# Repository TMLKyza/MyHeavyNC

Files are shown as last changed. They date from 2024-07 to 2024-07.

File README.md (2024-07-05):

# MyHeavyNC

Welcome to MyHeavyNC, a redesigned version of PrintNC. I'm open to suggestions and feedback on the project!

## About

First and foremost, I am **NOT** an engineer. I am a theoretical physicist who attempted to become an automation engineer but was unsuccessful in admission exams. As a result, there may be errors and areas for improvement in this project.

## File Structure and Features

The file structure is straightforward. In the `LCNC-config` folder, you will find everything you need to copy and paste into `~/linuxcnc/config` to get it working. This folder also contains a rewritten post processor for my cooling setup and partially rewritten Fusion360 probing routines.
Another thing I didn't like about how it was handled was tool-length-offsets and so I modifyed `M6remap` macro. Now, you only need to touch off the spindle cone on the tool setter and write the absolute measurement into the `.ini` file.
Because of this, I found no necessity to use the touchoff procedure used by QtDragon, so I rewired the button to the `M6` command.

To install in LinuxCNC all the above additions:
1. copy the `m6-remap` folder into ~/linuxcnc/nc_files/examples/
2. copy `f360-subroutines` into \~/linuxcnc/nc_files/examples
3. import in Fusion the new post processor `LCNC.cps`

## Why Choose This Project?

MyHeavyNC takes everything good from the original PrintNC project and makes it stiffer, heavier, and more powerful. The result is the ability to mill up to 100 cm³/min in aluminium and cut steel at 6000 rpm.
You can check out the performance of the machine on my [Instagram profile](https://www.instagram.com/diymachining/).

## Interesting details
1. I used a UHPC mix specifically made to anchor down machines that produce a lot of vibrations, it's also water and oil-resistant. The company that makes it is called Draco and the product is Flueco 75 if you wish to give a look at the datasheet.
2. The VFD I use is a really important component imo, I recently bought a Folinn BD600 with SVC. I had to sacrifice some top end as it has a maximum output frequency of 300hz in SVC but I gained a lot of torque everywhere in the rpm range. It's a bit more expensive but it makes a night and day difference.

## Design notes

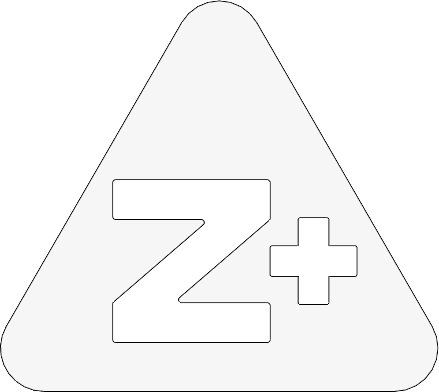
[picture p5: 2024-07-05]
LCNC-config/qtvcp/screens/qtdragon/images/z_plus_jog_button.png

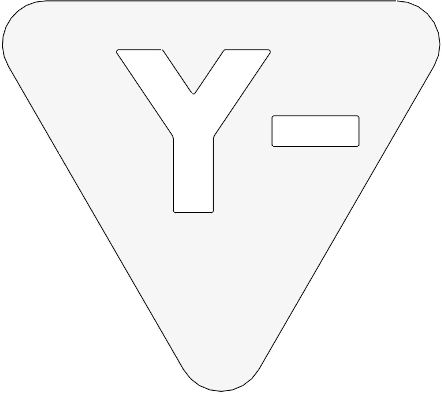
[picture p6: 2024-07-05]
LCNC-config/qtvcp/screens/qtdragon/images/y_minus_jog_button.png

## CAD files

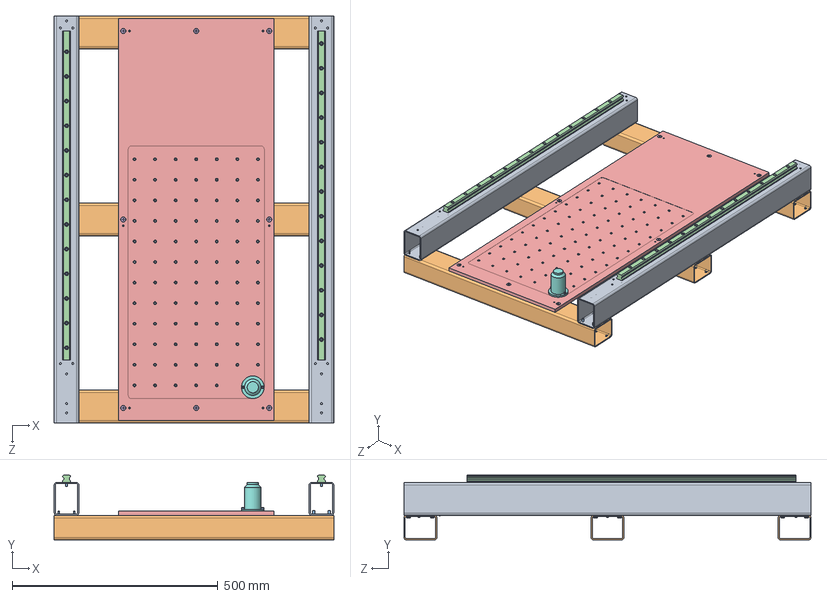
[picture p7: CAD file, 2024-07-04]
CAD/parts/Base/Base_assembly.SLDASM
680.0 x 158.0 x 990.0 mm
base_longitudinal_beams x 2
base_trasverse_beams x 3
socket head cap screw_am x 52
HRG25Rail x 2
socket countersunk head screw_am x 8
socket set screw cup point_am x 6
toolSetter^Base_assembly
hole_caps x 82

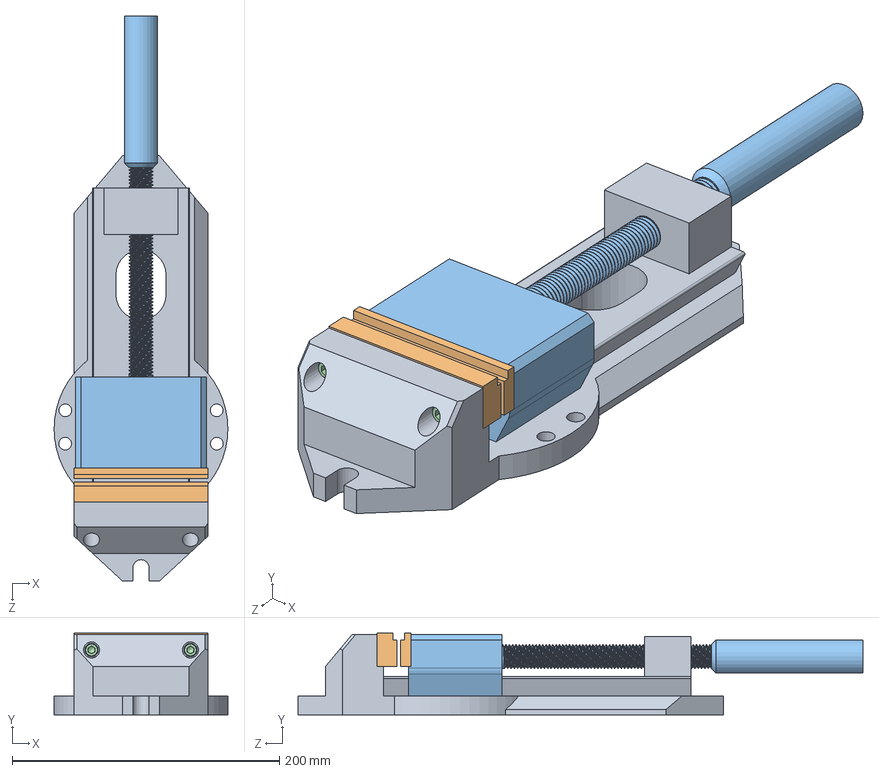
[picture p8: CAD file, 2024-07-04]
CAD/Users/CAD/Documents/SOLIDWORKS/vice/Vice.SLDASM
130.0 x 61.0 x 422.7 mm
base
jaws x 2
movingVice^Vice
socket head cap screw_am x 4

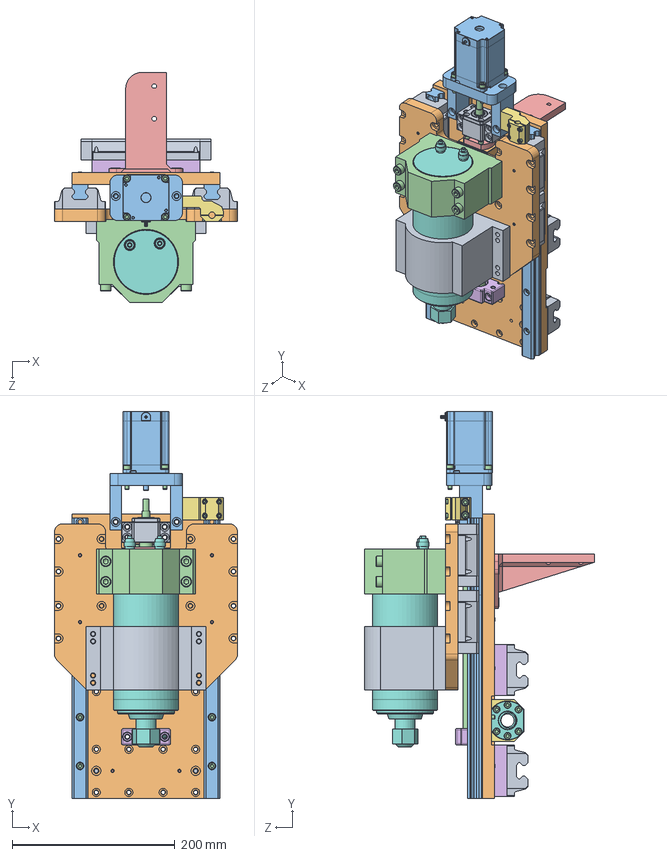
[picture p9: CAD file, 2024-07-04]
CAD/parts/Zaxis/ZAxis-assembly.SLDASM
225.2 x 475.8 x 283.0 mm
HRG25_Carriage x 8
mainPlate
HRG25Rail x 4
socket head cap screw_am x 34
socket set screw cup point_am x 8
XcarriageSpacer x 2
SFU16nutHolder.step
SFU1605-BallNut.step
BK10.step
SFU1204-nutCasing
nema23.step
SFU
SFU1204-BallNut.step
BF10_b___y___(___).STEP
608ZZ_b__.STEP
2_2kw_spindle v2.step
newSpindleSupport
spindlePlate
motorSupport
OldSpindleBracket.step
ZCableChainSupport.step
socket countersunk head screw_am x 3
Zsensor support^ZAxis-assembly

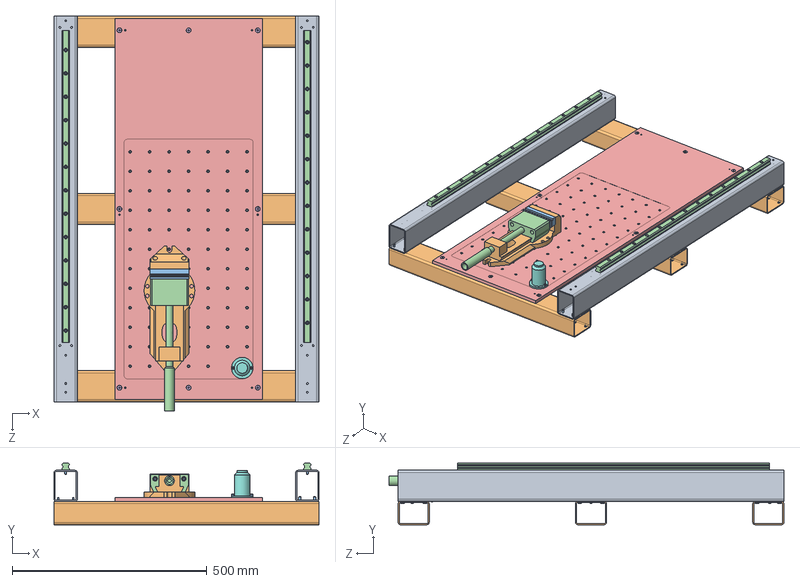
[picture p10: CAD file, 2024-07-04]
CAD/Users/CAD/Documents/SOLIDWORKS/Router/parts/Base/Base_assembly.SLDASM
680.0 x 158.0 x 1013.1 mm
base_longitudinal_beams x 2
base_trasverse_beams x 3
socket head cap screw_am x 56
HRG25Rail x 2
socket countersunk head screw_am x 8
socket set screw cup point_am x 6
toolSetter^Base_assembly
hole_caps x 82
base
jaws x 2
movingVice^Vice

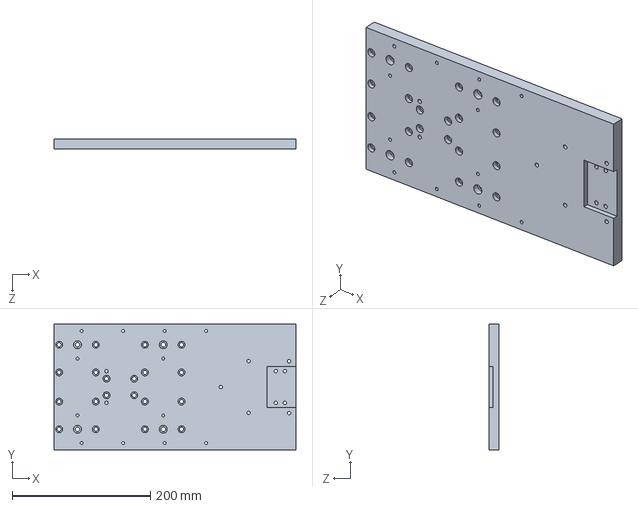
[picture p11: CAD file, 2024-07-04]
CAD/Users/CAD/Documents/SOLIDWORKS/Router/parts/Zaxis/mainPlate.SLDPRT
350.0 x 182.2 x 15.0 mm

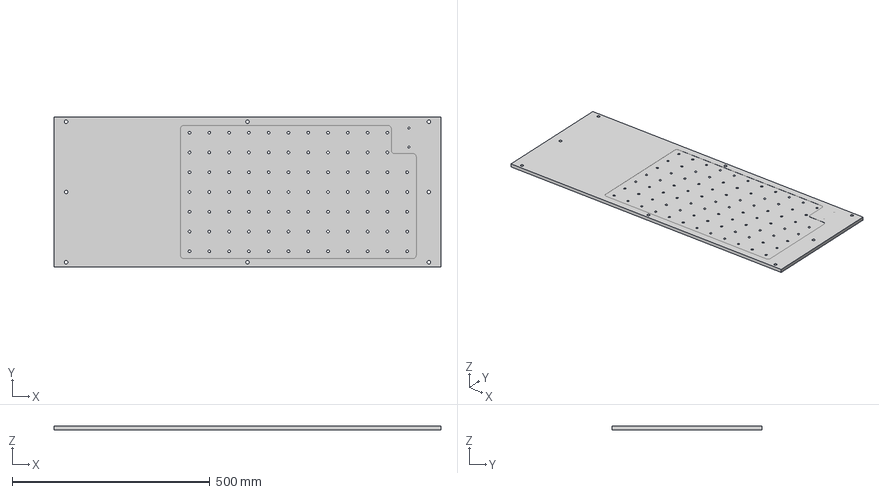
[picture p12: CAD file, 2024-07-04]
CAD/machineBed v8.step
978.0 x 379.0 x 10.0 mm

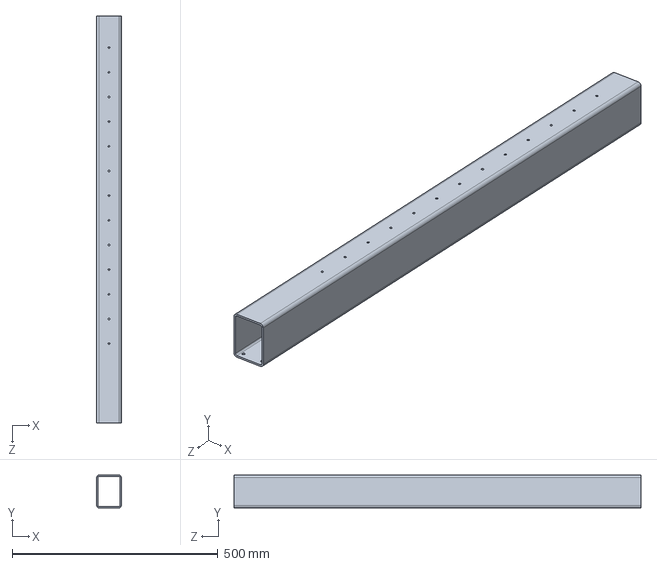
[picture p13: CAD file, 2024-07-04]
CAD/parts/Base/base_longitudinal_beams.SLDPRT
60.0 x 80.0 x 990.0 mm

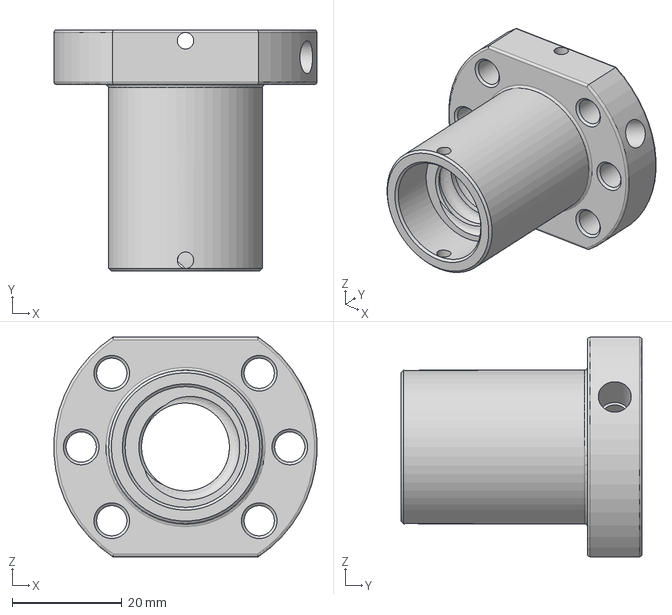
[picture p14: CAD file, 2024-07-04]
CAD/parts/SFU1605-BallNut.step
47.9 x 44.0 x 40.0 mm

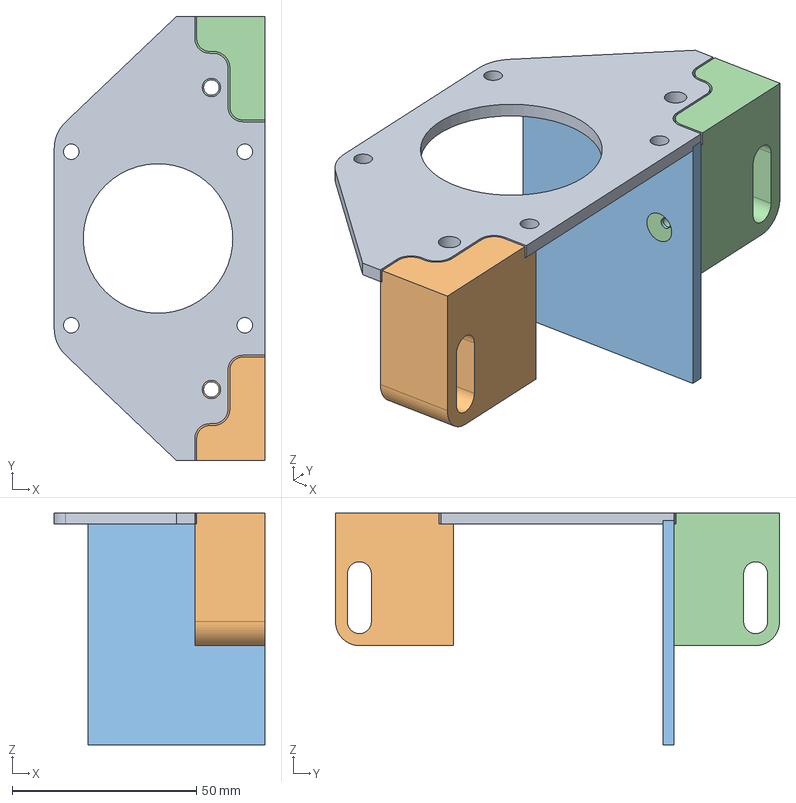
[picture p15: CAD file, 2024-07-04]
CAD/parts/Xaxis/XstepperMount.step
57.2 x 120.6 x 63.0 mm
stepperPlate
topBlock
supportPlate
bottomBlock

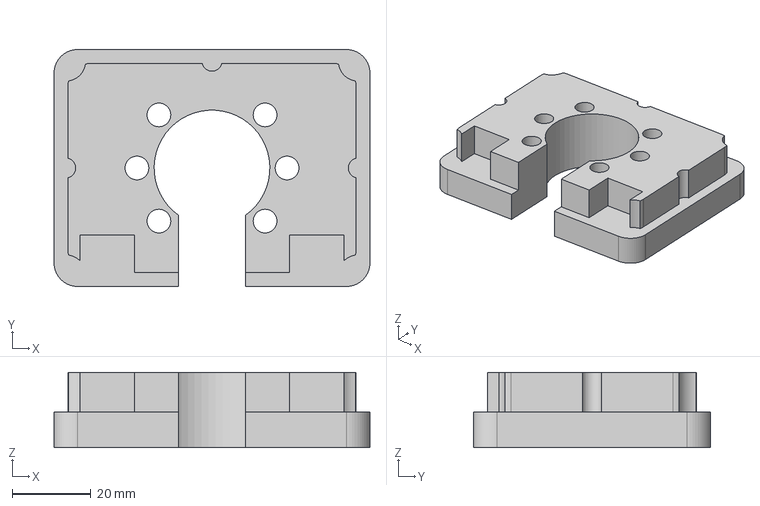
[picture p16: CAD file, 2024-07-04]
CAD/parts/Yaxis/Yplate_front.step
80.0 x 60.0 x 19.0 mm

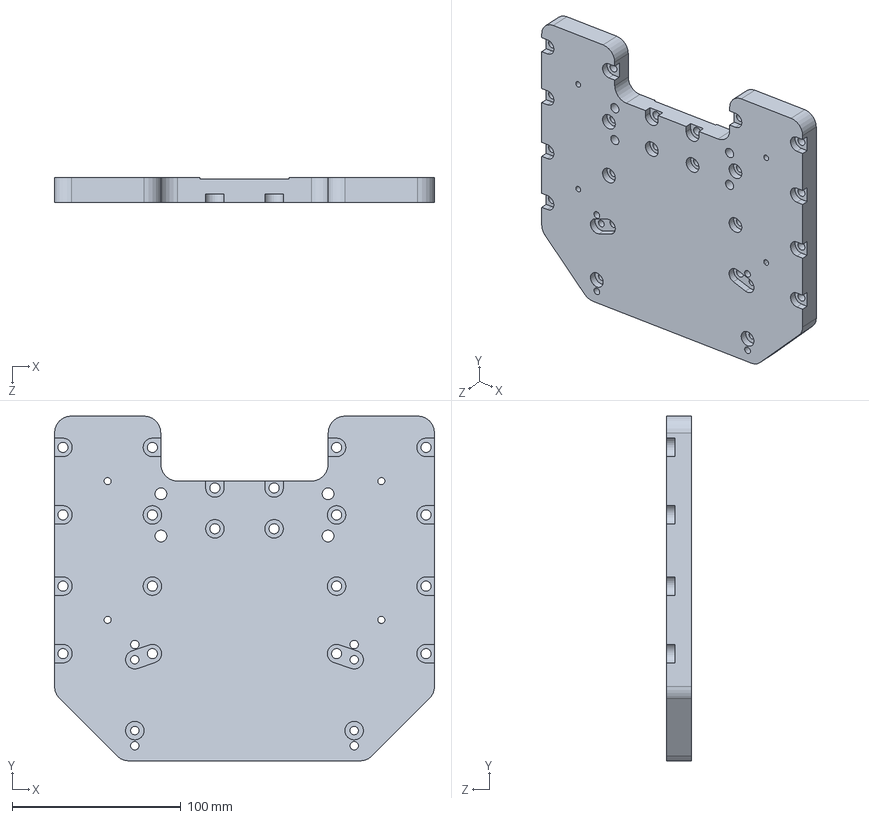
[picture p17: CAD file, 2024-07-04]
CAD/parts/Zaxis/spindlePlate.SLDPRT
225.2 x 204.4 x 15.0 mm

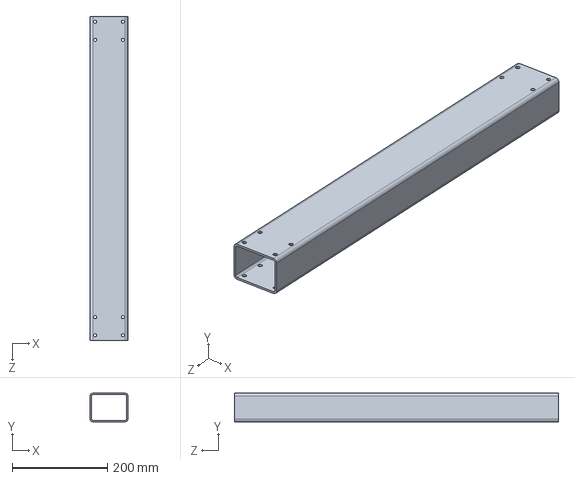
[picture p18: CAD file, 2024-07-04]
CAD/Users/CAD/Documents/SOLIDWORKS/Router/parts/Base/base_trasverse_beams.SLDPRT
80.0 x 60.0 x 680.0 mm

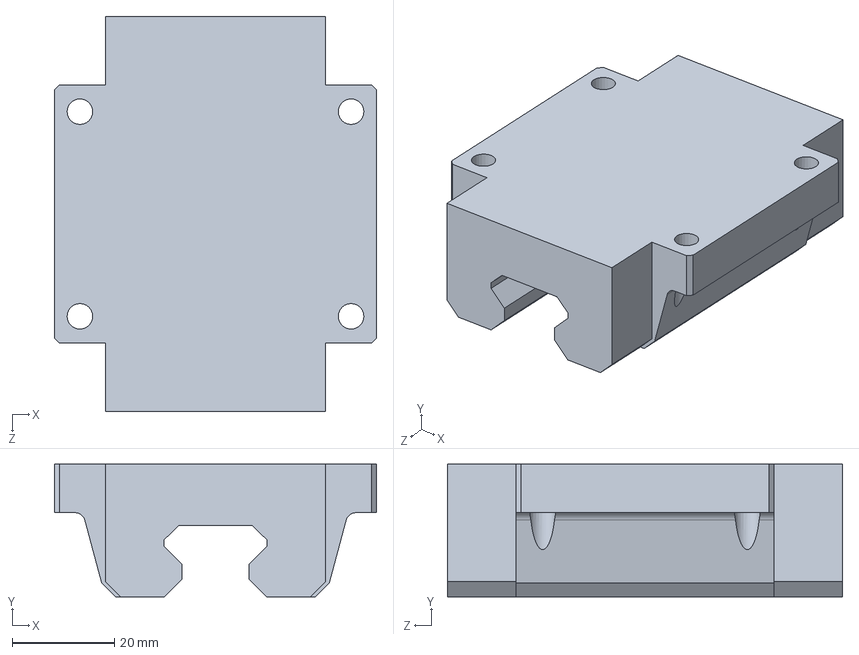
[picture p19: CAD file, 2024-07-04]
CAD/Users/CAD/Documents/SOLIDWORKS/Router/parts/HRG25_Carriage.SLDPRT
63.0 x 26.0 x 77.2 mm

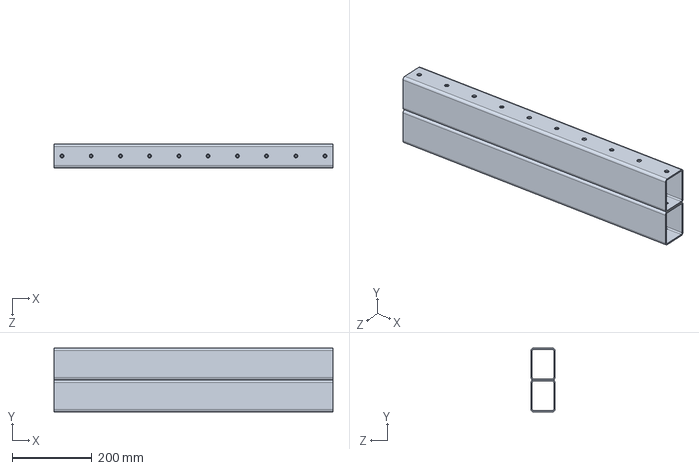
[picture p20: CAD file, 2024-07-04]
CAD/Users/CAD/Documents/SOLIDWORKS/Router/parts/Xaxis/X_tubes.SLDPRT
700.0 x 160.0 x 60.0 mm

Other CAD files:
CAD/Users/CAD/Documents/SOLIDWORKS/Router/parts/Zaxis/ZAxis-assembly.SLDASM
CAD/Users/CAD/Documents/SOLIDWORKS/Router/machineBed.SLDPRT
CAD/Users/CAD/Documents/SOLIDWORKS/Router/parts/Base/base_longitudinal_beams.SLDPRT
CAD/Users/CAD/Documents/SOLIDWORKS/Router/parts/Base/epoxygraniteCast.SLDPRT
CAD/Users/CAD/Documents/SOLIDWORKS/Router/parts/Base/hole_caps.SLDPRT
CAD/Users/CAD/Documents/SOLIDWORKS/Router/parts/HRG25Rail.SLDPRT
CAD/Users/CAD/Documents/SOLIDWORKS/Router/parts/SFU.SLDPRT
CAD/Users/CAD/Documents/SOLIDWORKS/Router/parts/Xaxis/XsensorSupport.SLDPRT
CAD/Users/CAD/Documents/SOLIDWORKS/Router/parts/Yaxis/BF12 Block.step
CAD/Users/CAD/Documents/SOLIDWORKS/Router/parts/Yaxis/BK12 Blocksupport.step
CAD/Users/CAD/Documents/SOLIDWORKS/Router/parts/Yaxis/Yaxis_tube.SLDPRT
CAD/Users/CAD/Documents/SOLIDWORKS/Router/parts/Yaxis/Yplate_rear.step
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

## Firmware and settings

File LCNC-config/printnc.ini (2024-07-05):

# Linuxcnc controller parameters for a simulated machine using QtDragon screen

# General note: Comments can either be preceded with a # or ; - either is
# acceptable, although # is in keeping with most linux config files.

[EMC]
VERSION = 1.1
MACHINE = qtdragon
DEBUG = 0x00000000

[DISPLAY]
# sets qtdragon as screen. for debug output to terminal add -d or -v
# sets window title
# sets icon in task manager
DISPLAY = qtvcp qtdragon
TITLE = QtDragon XYZ Auto Tool Probe
ICON = silver_dragon.png
USER_COMMAND_FILE = CONFIGFOLDER/qtdragonrc.py


# qtdragon saves most preference to this file
PREFERENCE_FILE_PATH = WORKINGFOLDER/qtdragon.pref

# min/max percentage overrides allowed in qtdragon 1 = 100%
MAX_FEED_OVERRIDE       = 2
MIN_SPINDLE_0_OVERRIDE    = 0
MAX_SPINDLE_0_OVERRIDE    = 2

# manual spindle speed will start at this RPM
DEFAULT_SPINDLE_0_SPEED   = 12000

# spindle up/down increment in RPM
SPINDLE_INCREMENT = 200

# min max apindle speed manually allowed 
MIN_SPINDLE_0_SPEED = 0
MAX_SPINDLE_0_SPEED = 18000

# max spindle power in Watts
MAX_SPINDLE_POWER = 2200

# min/max/default jog velocities in qtdragon in units/sec
MIN_LINEAR_VELOCITY     = 0
MAX_LINEAR_VELOCITY     = 60.00
DEFAULT_LINEAR_VELOCITY = 50.0

# incremental jog step length options
INCREMENTS = 10 mm, 1.0 mm, 0.10 mm, 0.01 mm

CYCLE_TIME = 100
INTRO_GRAPHIC = linuxcnc.gif
INTRO_TIME = 20

# default program search path
PROGRAM_PREFIX = /home/tmlkyza/linuxcnc/nc_files

# NGCGUI subroutine path.
# The path must also be in [RS274NGC] SUBROUTINE_PATH
NGCGUI_SUBFILE_PATH = ~/linuxcnc/nc_files/examples/ngcgui_lib/
# pre selected programs tabs
# specify filenames only, files must be in the NGCGUI_SUBFILE_PATH
NGCGUI_SUBFILE = slot.ngc
NGCGUI_SUBFILE = qpocket.ngc

# qtdragon saves rnning logs to this file
LOG_FILE = qtdragon.log

[MDI_COMMAND_LIST]
# for macro buttons on main oage up to 10 possible
MDI_COMMAND_MACRO0 = G53 G0 Z0;G0 X0 Y0;Z0, Goto\nUser\nZero
MDI_COMMAND_MACRO1 = G53 G0 Z0;G0 X0 Y0, Goto\nX-Y\nZero
MDI_COMMAND_MACRO2 = G53 G0 Z0;G53 G0 X0 Y0,Goto\nMachn\nZero

[FILTER]
# Controls what programs are shown inqtdragon file manager
PROGRAM_EXTENSION = .ngc,.nc,.tap G-Code File (*.ngc,*.nc,*.tap)
PROGRAM_EXTENSION = .png,.gif,.jpg Greyscale Depth Image
PROGRAM_EXTENSION = .py Python Script

# specifies what special 'filter' programs runs based on program ending
png = image-to-gcode
gif = image-to-gcode
jpg = image-to-gcode
py = python3

[KINS]
JOINTS = 4
KINEMATICS = trivkins coordinates=XYYZ 

[EMCIO]
EMCIO = io
CYCLE_TIME = 0.100
TOOL_TABLE = tool.tbl

[RS274NGC]
# motion controller saves parameters to this file
PARAMETER_FILE = qtdragon.var

# start up G/M codes when first loaded
RS274NGC_STARTUP_CODE = G17 G21 G40 G43H0 G54 G64P0.0127 G80 G90 G94 G97 M5 M9

# subroutine/remap path list
SUBROUTINE_PATH =\
~/linuxcnc/nc_files/examples/ngcgui_lib:\
~/linuxcnc/nc_files/examples/ngcgui_lib/utilitysubs:\
~/linuxcnc/nc_files/examples/m6-remap:\
~/linuxcnc/nc_files/examples/f360-subroutines:\
~/linuxcnc/nc_files/examples/remap_lib

# on abort, this ngc file is called. required for basic/versa probe
ON_ABORT_COMMAND=O <on_abort> call

# this remaps m6 to do auto probing after tool change
REMAP=M6 modalgroup=6 prolog=change_prolog ngc=qt_auto_probe_tool epilog=change_epilog

# required for python remaps
[PYTHON]
# The path to start a search for user modules. ie python's sys.path.insert(0,PATH)
PYTHON=/usr/bin/python3
PATH_PREPEND = /usr/lib/python3/dist-packages

# The path start point for all remap searches ie. python's sys.path.append() 
PATH_APPEND = ~/linuxcnc/nc_files/examples/remap_lib/python-stdglue/python
# path to the tremap's 'oplevel file
TOPLEVEL = ~/linuxcnc/nc_files/examples/remap_lib/python-stdglue/python/toplevel.py
# set remap debug level
#LOG_LEVEL = 1000

[EMCMOT]
EMCMOT = motmod
COMM_TIMEOUT = 1.0
BASE_PERIOD = 47000
SERVO_PERIOD = 1000000

[TASK]
TASK = milltask
CYCLE_TIME = 0.010

[TRAJ]
COORDINATES =  X Y Y Z
LINEAR_UNITS = mm
ANGULAR_UNITS = degree
DEFAULT_LINEAR_VELOCITY = 25.00
MAX_LINEAR_VELOCITY = 100.00
NO_FORCE_HOMING = 1
SPINDLES = 1

[HAL]
HALUI = halui
HALFILE = printnc.hal
# this file is loaded after qtdragon has made it's HAl pins
# you can add multiple entries
POSTGUI_HALFILE = qtdragon_postgui.hal

[HALUI]
# no content

[PROBE]
# pick basic probe or versa probe or remove for none

USE_PROBE = versaprobe
#USE_PROBE = basicprobe

[CHANGE_POSITION]
# Abs (G53) coordinates remap tool change point
X = 160
Y = 580
Z = 0

[VERSA_TOOLSETTER]
#toolsetter position on bed
X = 35
Y = 554
#rapid move above toolsetter
Z = 0
# how high to lift when moving to the tool setter
Z_MAX_CLEAR = 0
# tool setter diameter for diameter probing
DIAMETER = 20
# maximum machine units to lower while probing 
MAXPROBE = 120
# value of the ABS-Z axis when spindle bore (no collet nut) touches the tool setter
TS_HEIGHT=-147.48

[AXIS_X]
MAX_VELOCITY = 100
MAX_ACCELERATION = 1000
MIN_LIMIT = -0.001
MAX_LIMIT = 320

[JOINT_0]
TYPE = LINEAR
HOME = 0.0
MIN_LIMIT = -0.001
MAX_LIMIT = 320
MAX_VELOCITY = 100
MAX_ACCELERATION = 1000.0
STEPGEN_MAXACCEL = 1250
SCALE = 160.0981
FERROR = 1
MIN_FERROR = .25
HOME_OFFSET = -1.000000
HOME_SEARCH_VEL = -15.000000
HOME_LATCH_VEL = -1.500000
HOME_SEQUENCE = 1
HOME_IS_SHARED=1

[AXIS_Y]
MAX_VELOCITY = 100.0
MAX_ACCELERATION = 500.0
MIN_LIMIT = -0.001
MAX_LIMIT = 580.00

[JOINT_1]
TYPE = LINEAR
HOME = 0.0
MIN_LIMIT = -0.001
MAX_LIMIT = 580.00
MAX_VELOCITY = 100.0
MAX_ACCELERATION = 500.0
STEPGEN_MAXACCEL = 1250
SCALE = -160.0782
FERROR = 1
MIN_FERROR = .25
HOME_OFFSET = -6.42
HOME_SEARCH_VEL = -20.000000
HOME_LATCH_VEL = -5.000000
HOME_FINAL_VEL = 5.000000
HOME_SEQUENCE = -2
HOME_IS_SHARED=1

[JOINT_2]
TYPE = LINEAR
HOME = 0.0
MIN_LIMIT = -0.001
MAX_LIMIT = 580.00
MAX_VELOCITY = 100.0
MAX_ACCELERATION = 500.0
STEPGEN_MAXACCEL = 1250
SCALE = 160.0782
FERROR = 1
MIN_FERROR = .25
HOME_OFFSET = -5
HOME_SEARCH_VEL = -20.000000
HOME_LATCH_VEL = -5.000000
HOME_FINAL_VEL = 5.000000
HOME_SEQUENCE = -2

[AXIS_Z]
# used by external offsets for auto spindle lift and auto leveling
OFFSET_AV_RATIO  = 0.2
MAX_VELOCITY = 50.0
MAX_ACCELERATION = 250.0
MIN_LIMIT = -175.0
MAX_LIMIT = 0.001

[JOINT_3]
TYPE = LINEAR
HOME = 0.0
MIN_LIMIT = -175.0
MAX_LIMIT = 0.001
MAX_VELOCITY = 25.0
MAX_ACCELERATION = 250.0
STEPGEN_MAXACCEL = 937.5
SCALE = -400.2416
FERROR = 1
MIN_FERROR = .25
HOME_OFFSET = 1.000000
HOME_SEARCH_VEL = 15.00000
HOME_LATCH_VEL = 1.500000
HOME_SEQUENCE = 0
HOME_IS_SHARED=1

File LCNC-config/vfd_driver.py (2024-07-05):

import minimalmodbus
import time
import linuxcnc
import hal
import serial

# Initialize the Modbus connection
def initialize_vfd():
    try:
        vfd = minimalmodbus.Instrument('/dev/ttyUSB0', 1)  # Port name, slave address
        vfd.serial.baudrate = 9600
        vfd.serial.bytesize = 8
        vfd.serial.parity = serial.PARITY_NONE
        vfd.serial.stopbits = 1
        vfd.serial.timeout = 1
        return vfd
    except Exception as e:
        print("Failed to initialize VFD: {}".format(e))
        return None

vfd = initialize_vfd()
max_rpm = 18000
max_freq = 300

# HAL component
h = hal.component("vfd")
h.newpin("spindle-on", hal.HAL_BIT, hal.HAL_IN)
h.newpin("spindle-cw", hal.HAL_BIT, hal.HAL_IN)
h.newpin("spindle-ccw", hal.HAL_BIT, hal.HAL_IN)
h.newpin("spindle-speed", hal.HAL_FLOAT, hal.HAL_IN)
h.newpin("spindle-on-fault", hal.HAL_BIT, hal.HAL_OUT)
h.newpin("spindle-voltage", hal.HAL_FLOAT, hal.HAL_OUT)
h.newpin("spindle-current", hal.HAL_FLOAT, hal.HAL_OUT)
h.newpin("spindle-power", hal.HAL_FLOAT, hal.HAL_OUT)
h.newpin("spindle-torque", hal.HAL_FLOAT, hal.HAL_OUT)
h.newpin("spindle-running_speed", hal.HAL_FLOAT, hal.HAL_OUT)
h.newpin("spindle-fault", hal.HAL_U32, hal.HAL_OUT)
h.newpin("spindle-rps", hal.HAL_FLOAT, hal.HAL_OUT)
h.newpin("spindle-at-speed", hal.HAL_BIT, hal.HAL_OUT)
h.newpin("connection", hal.HAL_BIT, hal.HAL_OUT)
h.ready()

def rpm_to_perc(rpm):
    if abs(rpm) > max_rpm:
        return 0
    return abs(rpm / max_rpm)

def spindle_at_speed(set_rpm, current_rpm, variance):
    if current_rpm < set_rpm - variance or current_rpm > set_rpm + variance:
        return 0
    else:
        return 1

while True:
    try:
        if not vfd:
            vfd = initialize_vfd()
            if not vfd:
                time.sleep(1)
                continue

        time.sleep(0.01)
        #-----------------SPINDLE VFD--------------------
        set_freq = vfd.read_register(0x3001) / 100
        voltage = vfd.read_register(0x3003)
        current = vfd.read_register(0x3004) / 100
        power = vfd.read_register(0x3005)
        torque = vfd.read_register(0x3006)
        fault = vfd.read_register(0x8000)

        h['spindle-running_speed'] = set_freq / max_freq * max_rpm
        h['spindle-rps'] = set_freq / max_freq * max_rpm/60
        h['spindle-voltage'] = voltage
        h['spindle-current'] = current
        h['spindle-power'] = power
        h['spindle-torque'] = torque
        h['spindle-fault'] = fault

        if h['spindle-fault'] != 0:
            h['spindle-on-fault'] = True

        if h['spindle-on']:
            if h['spindle-cw']:
                vfd.write_register(0x1000, 1, 0, 6)
            if h['spindle-ccw']:
                vfd.write_register(0x1000, 2, 0, 6)
        else:
            vfd.write_register(0x1000, 6, 0, 6)

        vfd.write_register(0x3000, rpm_to_perc(h['spindle-speed']) * 10000, 0, 6)
        h['spindle-at-speed'] = spindle_at_speed(h['spindle-speed'], set_freq / max_freq * max_rpm, 100)
        h['connection'] = True  # Set communication status to true if no exceptions are raised

    except (minimalmodbus.NoResponseError, minimalmodbus.InvalidResponseError, 
            minimalmodbus.SlaveReportedException, serial.SerialException) as e:
        print("Communication error: {}".format(e))
        h['connection'] = False  # Set communication status to false if an error occurs
        vfd = None  # Reset vfd to trigger reconnection in the next loop
        time.sleep(1)
    except minimalmodbus.ModbusException as e:
        print("Modbus error: {}".format(e))
        h['connection'] = False  # Set communication status to false if an error occurs
        vfd = None  # Reset vfd to trigger reconnection in the next loop
        time.sleep(1)
    except Exception as e:
        print("Unexpected error: {}".format(e))
        h['connection'] = False  # Set communication status to false if an error occurs
        vfd = None  # Reset vfd to trigger reconnection in the next loop
        time.sleep(1)
    except KeyboardInterrupt:
        raise SystemExit

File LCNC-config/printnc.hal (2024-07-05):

# Generated by stepconf 1.1 at Wed Sep 20 16:43:17 2023
# If you make changes to this file, they will be
# overwritten when you run stepconf again
loadrt [KINS]KINEMATICS
loadrt [EMCMOT]EMCMOT base_period_nsec=[EMCMOT]BASE_PERIOD servo_period_nsec=[EMCMOT]SERVO_PERIOD num_joints=[KINS]JOINTS
loadrt hal_parport cfg="0 out"
setp parport.0.reset-time 1500
loadrt stepgen step_type=0,0,0,0
loadrt estop_latch
loadrt or2 count=2

addf parport.0.read base-thread
addf stepgen.make-pulses base-thread
addf parport.0.write base-thread
addf parport.0.reset base-thread

addf stepgen.capture-position servo-thread
addf motion-command-handler servo-thread
addf motion-controller servo-thread
addf stepgen.update-freq servo-thread
addf estop-latch.0 servo-thread
addf or2.0 servo-thread
addf or2.1 servo-thread

net spindle-fault-pause halui.program.pause

net estop-loopout iocontrol.0.emc-enable-in <= estop-latch.0.ok-out
net estop-loopin iocontrol.0.user-enable-out => estop-latch.0.ok-in
net estop-reset iocontrol.0.user-request-enable => estop-latch.0.reset
# ESTOP pin10
#net remote-estop estop-latch.0.fault-in <= parport.0.pin-10-in

#TS pin11
#probe pin12

net probe-in <= parport.0.pin-12-in-not
net length-in <= parport.0.pin-11-in
net probe-in => or2.0.in0
net length-in => or2.0.in1
net probe-or-length or2.0.out
net probe-or-length motion.probe-input

net xstep           => parport.0.pin-02-out
setp parport.0.pin-02-out-reset 1
net xdir            => parport.0.pin-03-out
net y1step           => parport.0.pin-04-out
setp parport.0.pin-04-out-reset 1
net y1dir            => parport.0.pin-05-out
net zstep           => parport.0.pin-06-out
setp parport.0.pin-06-out-reset 1
net zdir            => parport.0.pin-07-out
net y2step           => parport.0.pin-08-out
setp parport.0.pin-08-out-reset 1
net y2dir            => parport.0.pin-09-out
net home-y2         <= parport.0.pin-13-in
net home-x-y1-z     <= parport.0.pin-15-in-not

#define dumb variables for signal status
net mist-signal <= iocontrol.0.coolant-mist
net flood-signal <= iocontrol.0.coolant-flood

# or to activate air valve
net mist-signal => or2.1.in0
net flood-signal => or2.1.in1
net air-valve-signal <= or2.1.out

#drive the outputs
# Define pins for cooling
net air-valve-signal => parport.0.pin-17-out #air-valve
net mist-signal => parport.0.pin-16-out #oil-valve

setp stepgen.0.position-scale [JOINT_0]SCALE
setp stepgen.0.steplen 1
setp stepgen.0.stepspace 0
setp stepgen.0.dirhold 47000
setp stepgen.0.dirsetup 44000
setp stepgen.0.maxaccel [JOINT_0]STEPGEN_MAXACCEL
net xpos-cmd joint.0.motor-pos-cmd => stepgen.0.position-cmd
net xpos-fb stepgen.0.position-fb => joint.0.motor-pos-fb
net xstep <= stepgen.0.step
net xdir <= stepgen.0.dir
net xenable joint.0.amp-enable-out => stepgen.0.enable
net home-x-y1-z => joint.0.home-sw-in

setp stepgen.1.position-scale [JOINT_1]SCALE
setp stepgen.1.steplen 1
setp stepgen.1.stepspace 0
setp stepgen.1.dirhold 47000
setp stepgen.1.dirsetup 44000
setp stepgen.1.maxaccel [JOINT_1]STEPGEN_MAXACCEL
net y1pos-cmd joint.1.motor-pos-cmd => stepgen.1.position-cmd
net y1pos-fb stepgen.1.position-fb => joint.1.motor-pos-fb
net y1step <= stepgen.1.step
net y1dir <= stepgen.1.dir
net y1enable joint.1.amp-enable-out => stepgen.1.enable
net home-x-y1-z => joint.1.home-sw-in

setp stepgen.2.position-scale [JOINT_2]SCALE
setp stepgen.2.steplen 1
setp stepgen.2.stepspace 0
setp stepgen.2.dirhold 47000
setp stepgen.2.dirsetup 44000
setp stepgen.2.maxaccel [JOINT_2]STEPGEN_MAXACCEL
net y2pos-cmd joint.2.motor-pos-cmd => stepgen.2.position-cmd
net y2pos-fb stepgen.2.position-fb => joint.2.motor-pos-fb
net y2step <= stepgen.2.step
net y2dir <= stepgen.2.dir
net y2enable joint.2.amp-enable-out => stepgen.2.enable
net home-y2 => joint.2.home-sw-in

setp stepgen.3.position-scale [JOINT_3]SCALE
setp stepgen.3.steplen 1
setp stepgen.3.stepspace 0
setp stepgen.3.dirhold 47000
setp stepgen.3.dirsetup 44000
setp stepgen.3.maxaccel [JOINT_3]STEPGEN_MAXACCEL
net zpos-cmd joint.3.motor-pos-cmd => stepgen.3.position-cmd
net zpos-fb stepgen.3.position-fb => joint.3.motor-pos-fb
net zstep <= stepgen.3.step
net zdir <= stepgen.3.dir
net zenable joint.3.amp-enable-out => stepgen.3.enable
net home-x-y1-z => joint.3.home-sw-in

# Include the VFD HAL configuration
source vfd.hal

#net estop-out <= iocontrol.0.user-enable-out
#net estop-ext => iocontrol.0.emc-enable-in

#loadusr -W hal_manualtoolchange
#net tool-change iocontrol.0.tool-change => hal_manualtoolchange.change
#net tool-changed iocontrol.0.tool-changed <= hal_manualtoolchange.changed
#net tool-number iocontrol.0.tool-prep-number => hal_manualtoolchange.number
net tool-prepare-loopback iocontrol.0.tool-prepare => iocontrol.0.tool-prepared
